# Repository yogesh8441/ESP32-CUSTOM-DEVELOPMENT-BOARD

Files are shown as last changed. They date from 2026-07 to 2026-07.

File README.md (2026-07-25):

# ESP32-CUSTOM-DEVELOPMENT-BOARD

A custom-designed **ESP32-WROOM-32D Development Board** developed using **KiCad 10**. This project demonstrates the complete PCB design workflow, including schematic design, PCB layout, routing, ground plane implementation, ERC/DRC verification, and generation of manufacturing-ready Gerber files.

---

## 📖 Project Overview

This development board is designed for embedded systems and IoT applications. The board integrates the ESP32-WROOM-32D module with USB programming, power regulation, communication interfaces, and peripheral connectors while following standard PCB design practices.

---

## ✨ Features

- ESP32-WROOM-32D Microcontroller
- CH340C USB-to-UART Interface
- AP2112K-3.3 Voltage Regulator
- USB Programming Support
- UART Communication
- GPIO Expansion Headers
- 16×2 LCD Interface
- 7-Segment Display Interface
- VSPI Interface
- Crystal Oscillator Circuit
- Decoupling Capacitors
- 2-Layer PCB Design
- Ground Plane Implementation
- ERC & DRC Verified
- Manufacturing Ready Gerber Files

---

# 📷 Project Images

## Schematic

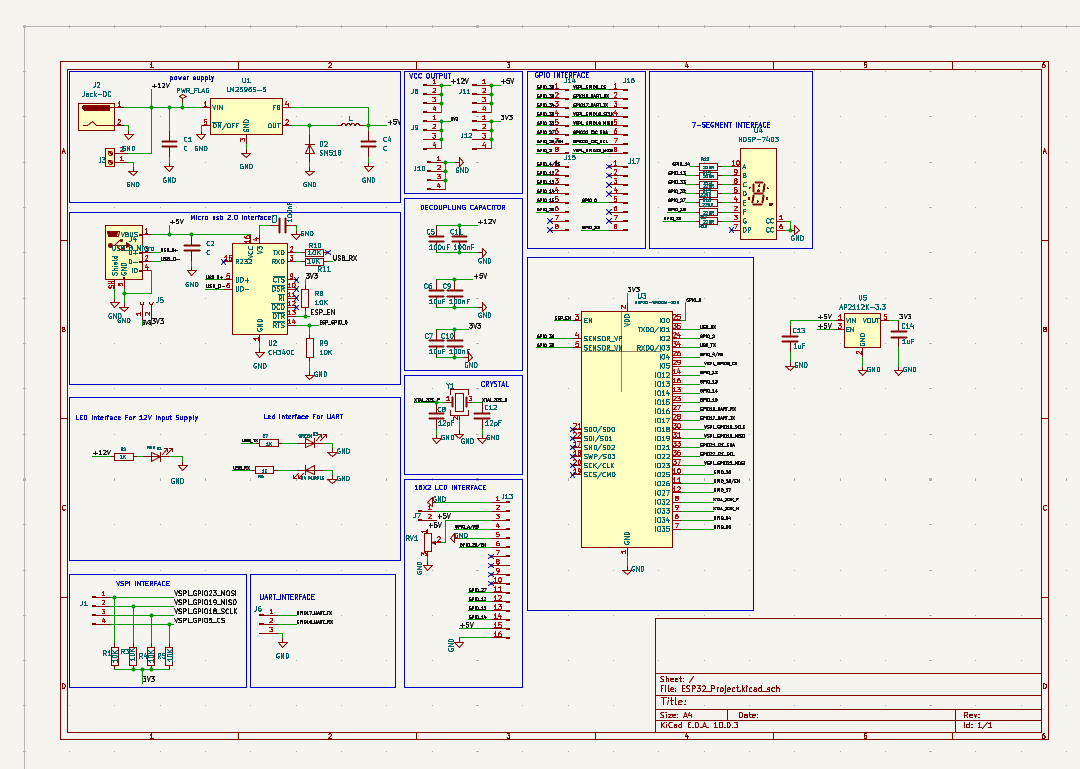
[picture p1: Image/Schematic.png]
Schematic


---

## PCB Top View

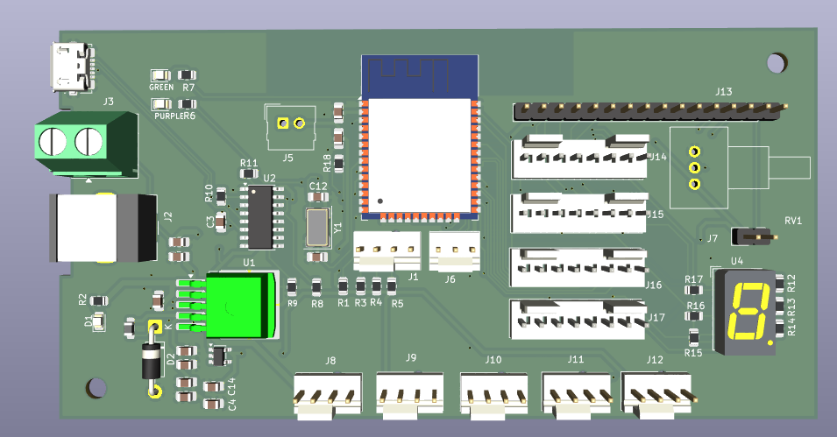
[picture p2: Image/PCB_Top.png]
PCB Top


---

## PCB Bottom View

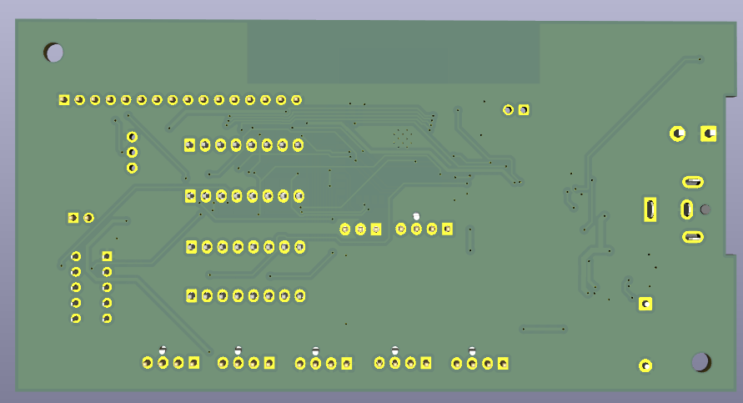
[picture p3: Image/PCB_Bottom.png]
PCB Bottom


---

## ⚙️ Hardware Specifications

| Parameter | Specification |
|---|---|
| Microcontroller | ESP32-WROOM-32D |
| USB Interface | CH340C |
| Voltage Regulator | AP2112K-3.3 |
| PCB Layers | 2 |
| PCB Thickness | 1.6 mm |
| Copper Thickness | 1 oz |
| PCB Software | KiCad 10 |
| Manufacturing | JLCPCB Compatible |

---

## 📁 Repository Structure

```text
ESP32-CUSTOM-DEVELOPMENT-BOARD/
│
├── Image/
│   ├── PCB_Top.png
│   ├── PCB_Bottom.png
│   └── Schematic.png
│
├── Schematic/
│   └── ESP32_Project.kicad_sch
│
├── PCB/
│   └── ESP32_Project.kicad_pcb
│
├── Gerber/
│   └── ESP32_Gerber.zip
│
├── Documents/
│
├── README.md
└── LICENSE
```

---

## 🔄 PCB Design Workflow

1. Requirement Analysis
2. Circuit Design
3. Schematic Capture
4. Footprint Assignment
5. PCB Component Placement
6. PCB Routing
7. Ground Plane Implementation
8. ERC Verification
9. DRC Verification
10. Gerber File Generation
11. PCB Manufacturing

---

## 🏭 Manufacturing

The generated Gerber files are manufacturing-ready and can be directly uploaded to PCB fabrication services such as:

- JLCPCB
- PCBWay
- NextPCB

---

## 🚀 Future Improvements

- USB Type-C Interface
- ESD Protection
- Reverse Polarity Protection
- Test Points
- Buck Converter Based Power Supply
- Improved EMI/EMC Performance

---

## 👨‍💻 Author

**Yogesh Kumar**

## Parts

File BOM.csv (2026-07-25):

Id | Designator | Footprint | Quantity | Designation | Supplier and ref
1 | C1, C2, C4 | C_0805_2012Metric_Pad1.18x1.45mm_HandSolder | 3 | C
2 | C3, C9, C10, C11 | C_0805_2012Metric_Pad1.18x1.45mm_HandSolder | 4 | 100nF
3 | C5 | C_0805_2012Metric_Pad1.18x1.45mm_HandSolder | 1 | 100uF
4 | C6, C7 | C_0805_2012Metric_Pad1.18x1.45mm_HandSolder | 2 | 10uF
5 | C8, C12 | C_0805_2012Metric_Pad1.18x1.45mm_HandSolder | 2 | 12pF
6 | C13, C14 | C_0805_2012Metric_Pad1.18x1.45mm_HandSolder | 2 | 1uF
7 | D1 | LED_0805_2012Metric | 1 | RED
8 | D2 | D_DO-41_SOD81_P10.16mm_Horizontal | 1 | SM518
9 | D3 | LED_0805_2012Metric | 1 | GREEN
10 | D4 | LED_0805_2012Metric | 1 | PURPLE
11 | J1, J8, J9, J10, J11, J12 | FanPinHeader_1x04_P2.54mm_Vertical | 6 | Conn_01x04_Pin
12 | J2 | BarrelJack_CUI_PJ-063AH_Horizontal | 1 | Jack-DC
13 | J3 | TerminalBlock_Phoenix_MKDS-1,5-2-5.08_1x02_P5.08mm_Horizontal | 1 | Screw_Terminal_01x02
14 | J4 | USB_Micro-B_Molex_47346-0001 | 1 | USB_B_Micro
15 | J5 | Molex_SL_171971-0002_1x02_P2.54mm_Vertical | 1 | Conn_01x02_Socket
16 | J6 | FanPinHeader_1x03_P2.54mm_Vertical | 1 | Conn_01x03_Pin
17 | J7 | PinHeader_1x02_P2.54mm_Vertical | 1 | Conn_01x02_Pin
18 | J13 | PinHeader_1x16_P2.54mm_Vertical | 1 | Conn_01x16_Pin
19 | J14, J15, J16, J17 | Molex_KK-254_AE-6410-08A_1x08_P2.54mm_Vertical | 4 | Conn_01x08_Pin
20 | L1 | L_0805_2012Metric_Pad1.05x1.20mm_HandSolder | 1 | L
21 | R1, R3, R4, R5, R8, R9, R10, R11 | R_0805_2012Metric | 8 | 10K
22 | R2, R6, R7 | R_0805_2012Metric | 3 | 1K
23 | R12, R13, R14, R15, R16, R17, R18 | R_0805_2012Metric | 7 | 220R
24 | RV1 | Potentiometer_Vishay_148-149_Single_Horizontal | 1 | 10k
25 | U1 | TO-263-5_TabPin3 | 1 | LM2596S-5
26 | U2 | SOIC-16_3.9x9.9mm_P1.27mm | 1 | CH340C
27 | U3 | ESP32-WROOM-32D | 1 | ESP32-WROOM-32D
28 | U4 | HDSP-7401 | 1 | HDSP-7403
29 | U5 | SOT-23-5 | 1 | AP2112K-3.3
30 | Y1 | Crystal_SMD_0603-4Pin_6.0x3.5mm | 1 | Crystal_GND24

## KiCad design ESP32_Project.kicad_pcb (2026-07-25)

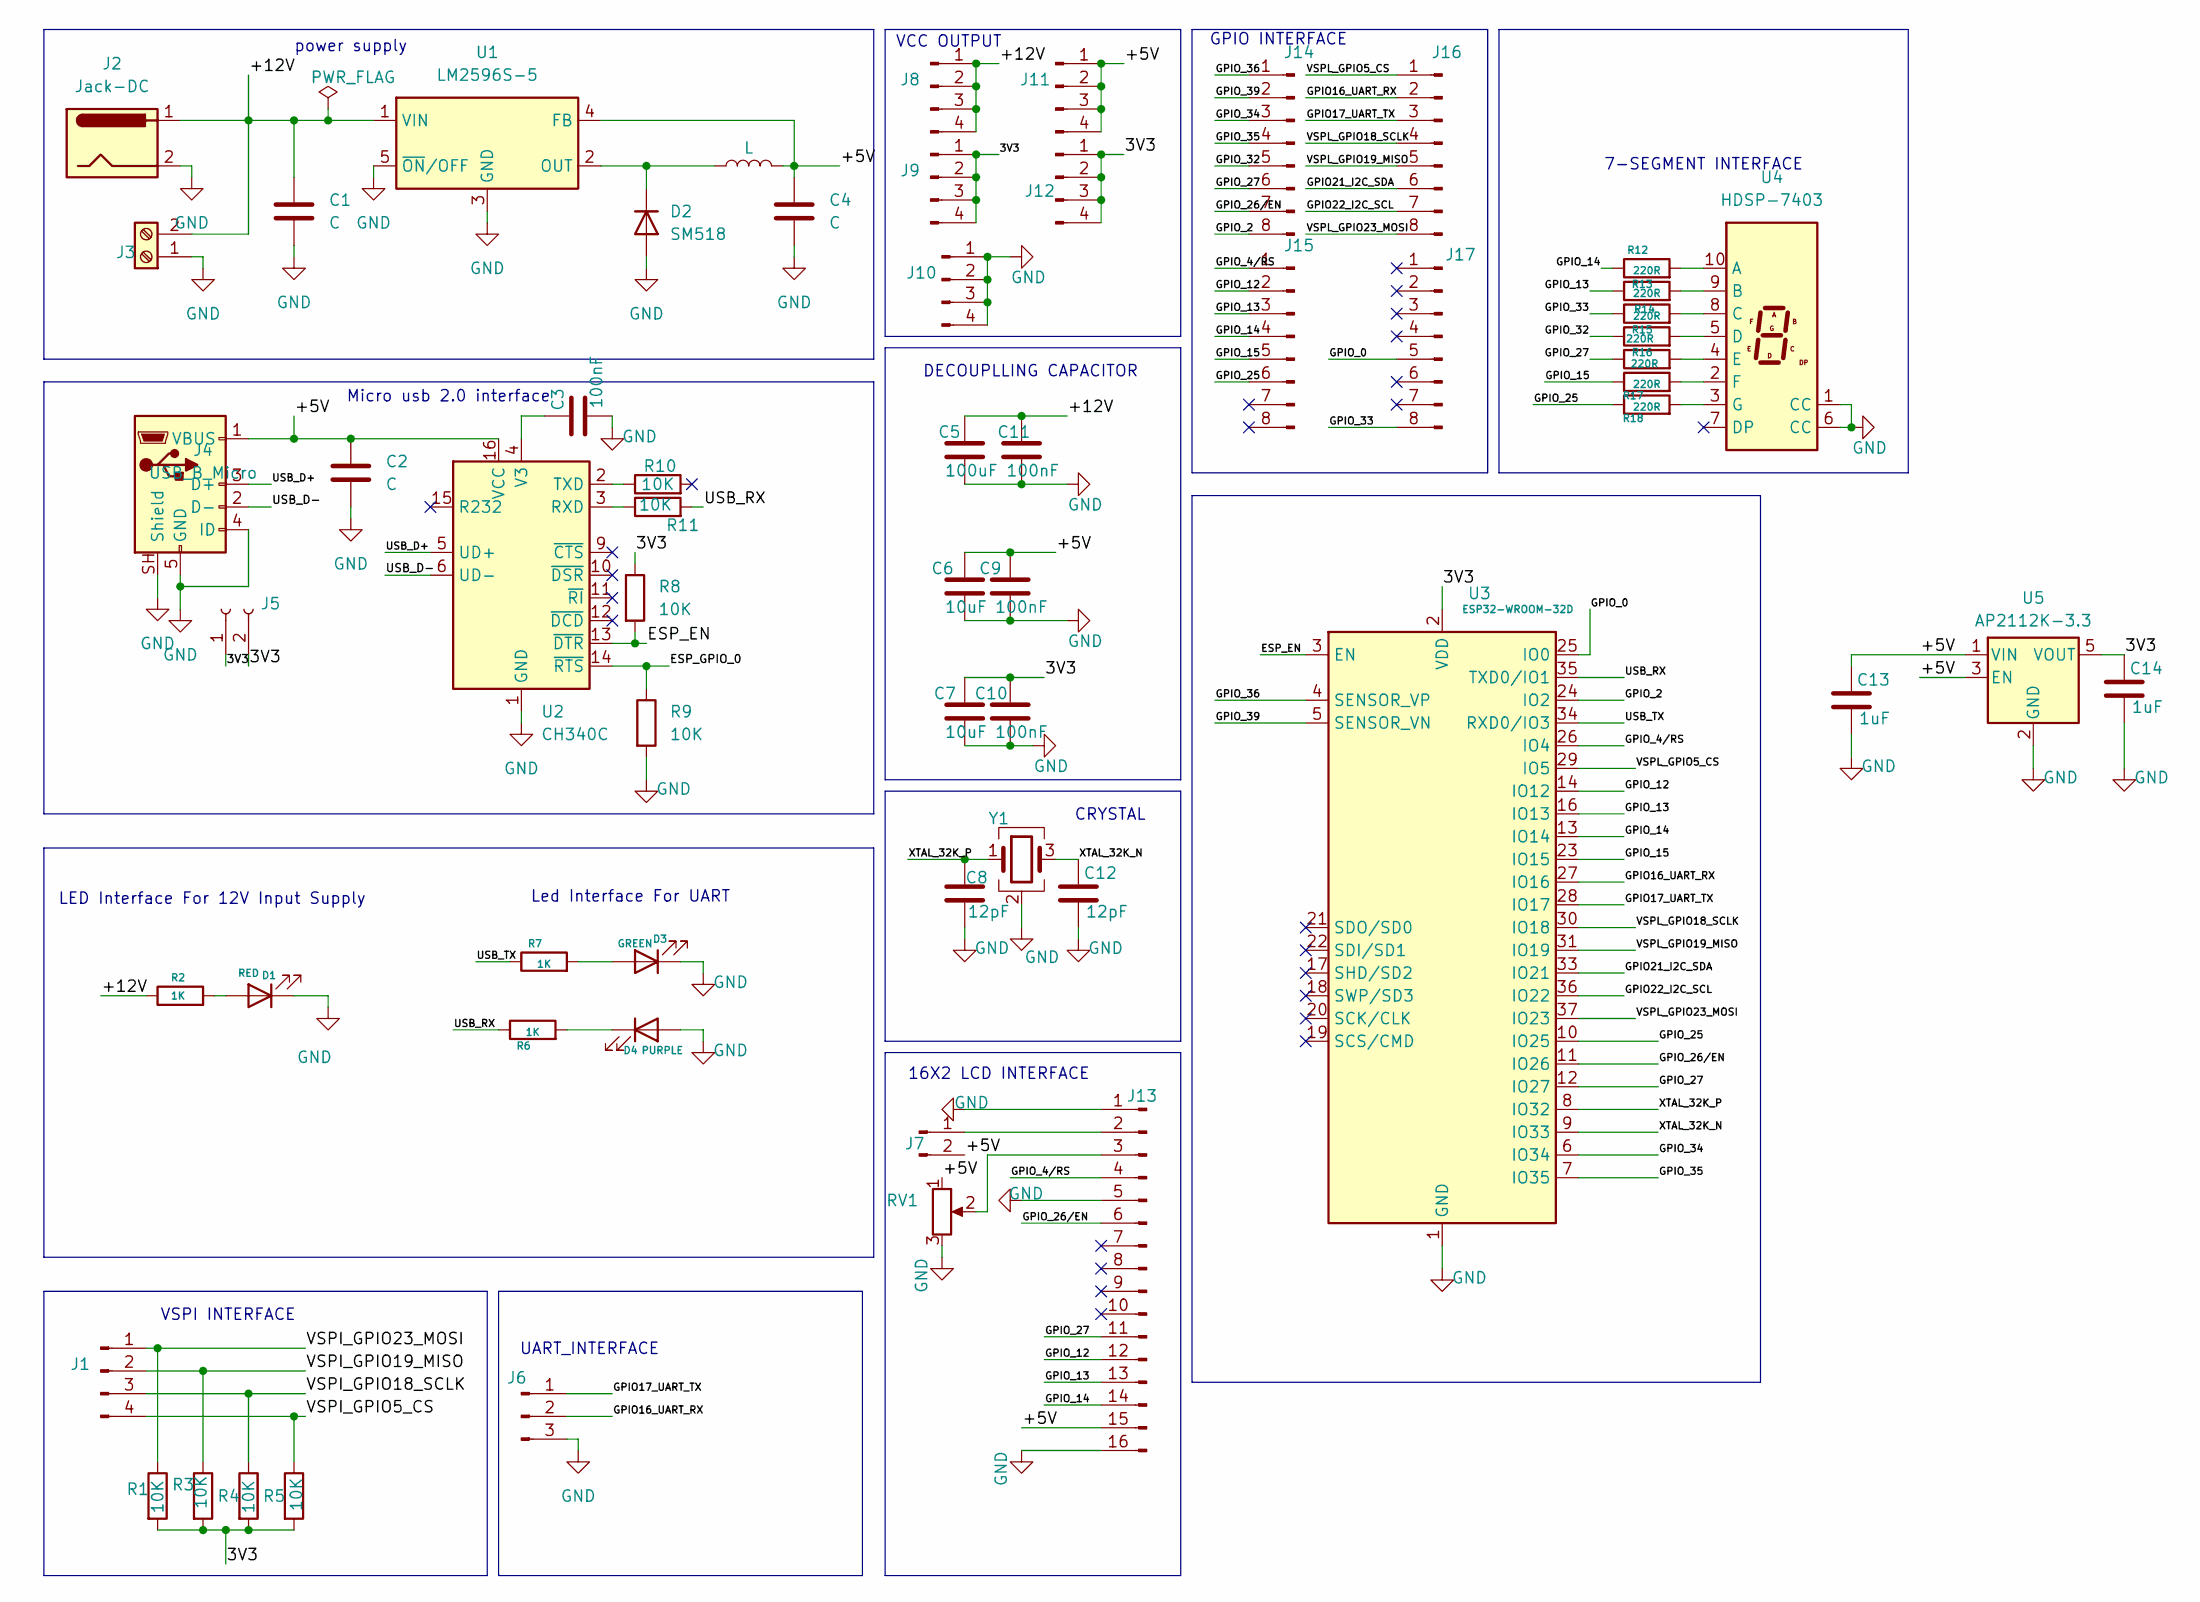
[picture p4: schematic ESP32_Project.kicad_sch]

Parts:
C1, C2, C4: C; C_0805_2012Metric_Pad1.18x1.45mm_HandSolder
C3, C9, C10, C11: 100nF; C_0805_2012Metric_Pad1.18x1.45mm_HandSolder
C5: 100uF; C_0805_2012Metric_Pad1.18x1.45mm_HandSolder
C6, C7: 10uF; C_0805_2012Metric_Pad1.18x1.45mm_HandSolder
C8, C12: 12pF; C_0805_2012Metric_Pad1.18x1.45mm_HandSolder
C13, C14: 1uF; C_0805_2012Metric_Pad1.18x1.45mm_HandSolder
D1: RED; LED_0805_2012Metric
D2: SM518; D_DO-41_SOD81_P10.16mm_Horizontal
D3: GREEN; LED_0805_2012Metric
D4: PURPLE; LED_0805_2012Metric
J1, J8, J9, J10, J11, J12: Conn_01x04_Pin; FanPinHeader_1x04_P2.54mm_Vertical
J2: Jack-DC; BarrelJack_SwitchcraftConxall_RAPC10U_Horizontal
J3: Screw_Terminal_01x02; TerminalBlock_Phoenix_MKDS-1,5-2-5.08_1x02_P5.08mm_Horizont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
J4: USB_B_Micro; USB_Micro-AB_Molex_47590-0001
J5: Conn_01x02_Socket; Molex_SL_171971-0002_1x02_P2.54mm_Vertical
J6: Conn_01x03_Pin; FanPinHeader_1x03_P2.54mm_Vertical
J7: Conn_01x02_Pin; PinHeader_1x02_P2.54mm_Vertical
J13: Conn_01x16_Pin; PinHeader_1x16_P2.54mm_Vertical
J14, J15, J16, J17: Conn_01x08_Pin; Molex_KK-254_AE-6410-08A_1x08_P2.54mm_Vertical
L1: L; L_0805_2012Metric_Pad1.05x1.20mm_HandSolder
R1, R3, R4, R5, R8, R9, R10, R11: 10K; R_0805_2012Metric
R2, R6, R7: 1K; R_0805_2012Metric
R12, R13, R14, R15, R16, R17, R18: 220R; R_0805_2012Metric
RV1: R_Potentiometer; Potentiometer_Vishay_148-149_Single_Horizontal
U1: LM2596S-5; TO-263-5_TabPin3
U2: CH340C; SOIC-16_3.9x9.9mm_P1.27mm
U3: ESP32-WROOM-32D
U4: HDSP-7403; HDSP-7401
U5: AP2112K-3.3; SOT-23-5
Y1: Crystal_GND24; Crystal_SMD_0603-4Pin_6.0x3.5mm

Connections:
/3V3: C7.1, C10.1, C14.1, J5.1, J5.2, J9.1, J9.2, J9.3, J9.4, J12.1, J12.2, J12.3, J12.4, R1.2, R3.2, R4.2, R5.2, R8.1, U3.2 (VDD), U5.5 (VOUT)
/+5V: C2.1, C4.1, C6.1, C9.1, C13.1, J4.1 (VBUS), J7.2, J11.1, J11.2, J11.3, J11.4, J13.15, L1.2, RV1.1, U1.4 (FB), U2.16 (VCC), U5.1 (VIN), U5.3 (EN)
/+12V: C1.1, C5.1, C11.1, J2.1, J3.2, J8.1, J8.2, J8.3, J8.4, R2.1, U1.1 (VIN)
/ESP_EN: R8.2, U2.13 (~DTR), U3.3 (EN)
/ESP_GPIO_0: R9.1, U2.14 (~RTS)
/GPIO16_UART_RX: J6.2, J16.2, U3.27 (IO16)
/GPIO17_UART_TX: J6.1, J16.3, U3.28 (IO17)
/GPIO21_I2C_SDA: J16.6, U3.33 (IO21)
/GPIO22_I2C_SCL: J16.7, U3.36 (IO22)
/GPIO_0: J17.5, U3.25 (IO0)
/GPIO_2: J14.8, U3.24 (IO2)
/GPIO_4/RS: J13.4, J15.1, U3.26 (IO4)
/GPIO_12: J13.12, J15.2, U3.14 (IO12)
/GPIO_13: J13.13, J15.3, R13.1, U3.16 (IO13)
/GPIO_14: J13.14, J15.4, R12.1, U3.13 (IO14)
/GPIO_15: J15.5, R17.1, U3.23 (IO15)
/GPIO_25: J15.6, R18.1, U3.10 (IO25)
/GPIO_26/EN: J13.6, J14.7, U3.11 (IO26)
/GPIO_27: J13.11, J14.6, R16.1, U3.12 (IO27)
/GPIO_32: J14.5, R15.1
/GPIO_33: J17.8, R14.1
/GPIO_34: J14.3, U3.6 (IO34)
/GPIO_35: J14.4, U3.7 (IO35)
/GPIO_36: J14.1, U3.4 (SENSOR_VP)
/GPIO_39: J14.2, U3.5 (SENSOR_VN)
/USB_D+: J4.3 (D+), U2.5 (UD+)
/USB_D-: J4.2 (D-), U2.6 (UD-)
/USB_RX: R6.1, R11.2, U3.35 (TXD0/IO1)
/USB_TX: R7.1, U3.34 (RXD0/IO3)
/VSPI_GPIO5_CS: J1.4, R5.1
/VSPI_GPIO18_SCLK: J1.3, R4.1
/VSPI_GPIO19_MISO: J1.2, R3.1
/VSPI_GPIO23_MOSI: J1.1, R1.1
/VSPL_GPIO5_CS: J16.1, U3.29 (IO5)
/VSPL_GPIO18_SCLK: J16.4, U3.30 (IO18)
/VSPL_GPIO19_MISO: J16.5, U3.31 (IO19)
/VSPL_GPIO23_MOSI: J16.8, U3.37 (IO23)
/XTAL_32K_N: C12.1, U3.9 (IO33), Y1.3
/XTAL_32K_P: C8.1, U3.8 (IO32), Y1.1
GND: C1.2, C2.2, C3.2, C4.2, C5.2, C6.2, C7.2, C8.2, C9.2, C10.2, C11.2, C12.2, C13.2, C14.2, D1.1 (K), D2.2 (A), D3.1 (K), D4.2 (A), J2.2, J3.1, J4.4 (ID), J4.5 (GND), J4.SH (Shield), J6.3, J10.1, J10.2, J10.3, J10.4, J13.1, J13.5, J13.16, R9.2, RV1.3, U1.3 (GND), U1.5 (~ON/OFF), U2.1 (GND), U3.1 (GND), U3.15 (GND), U3.38 (GND), U3.39 (GND), U4.1 (CC), U4.6 (CC), U5.2 (GND), Y1.2 (G), Y1.4 (G)
unnamed: D1.2 (A), R2.2
unnamed: D2.1 (K), L1.1, U1.2 (OUT)
unnamed: D3.2 (A), R7.2
unnamed: D4.1 (K), R6.2
unnamed: J7.1, J13.2
unnamed: J13.3, RV1.2
unnamed: R11.1, U2.3 (RXD)
unnamed: R10.1, U2.2 (TXD)
unnamed: C3.1, U2.4 (V3)
unnamed: R12.2, U4.10 (A)
unnamed: R13.2, U4.9 (B)
unnamed: R14.2, U4.8 (C)
unnamed: R15.2, U4.5 (D)
unnamed: R16.2, U4.4 (E)
unnamed: R17.2, U4.2 (F)
unnamed: R18.2, U4.3 (G)

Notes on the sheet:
CRYSTAL
GPIO INTERFACE
power supply
VSPI INTERFACE
7-SEGMENT INTERFACE
Micro usb 2.0 interface
DECOUPLLING CAPACITOR
16X2 LCD INTERFACE
VCC OUTPUT
LED Interface For 12V Input Supply
UART_INTERFACE
Led Interface For UART

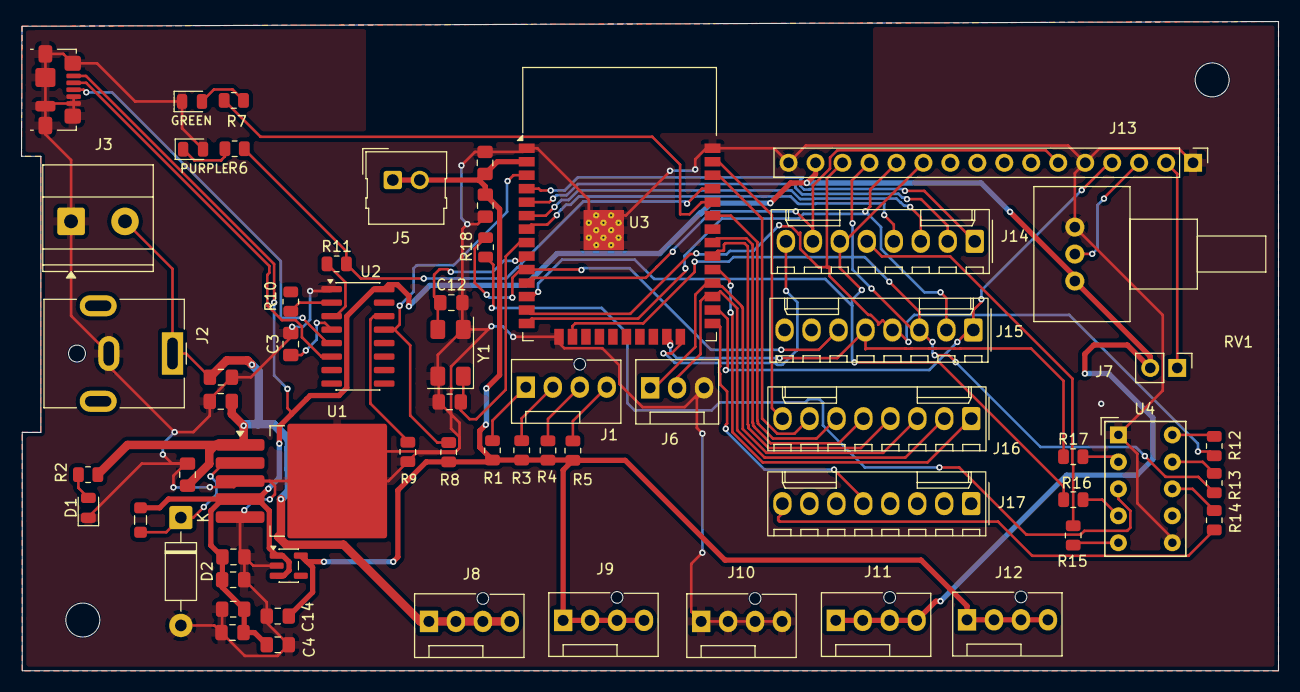
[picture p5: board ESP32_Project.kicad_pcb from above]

Board: 2 copper layers, 118.4 x 61.2 mm, 61 parts (0 on the bottom side), 56 nets.
